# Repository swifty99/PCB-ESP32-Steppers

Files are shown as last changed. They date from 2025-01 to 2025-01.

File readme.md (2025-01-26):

# PCB-ESP32-Stepper

## Description

This project features a **PCB design for ESP32 development boards** (DevKit). It is designed to host ESP32 boards and provides a robust platform for controlling stepper motors. The PCB includes two slots for stepper motor drivers, supporting both simple drivers and more advanced ones such as **Fysetc Trinamic drivers**. Additionally, the board offers extra connectors for **I2C** or general-purpose **IOs**.

For control, the board is compatible with **FluidNC** firmware, which is a great solution for CNC machines and other motion control applications.

### Project Images

#### 3D Screenshot of the PCB
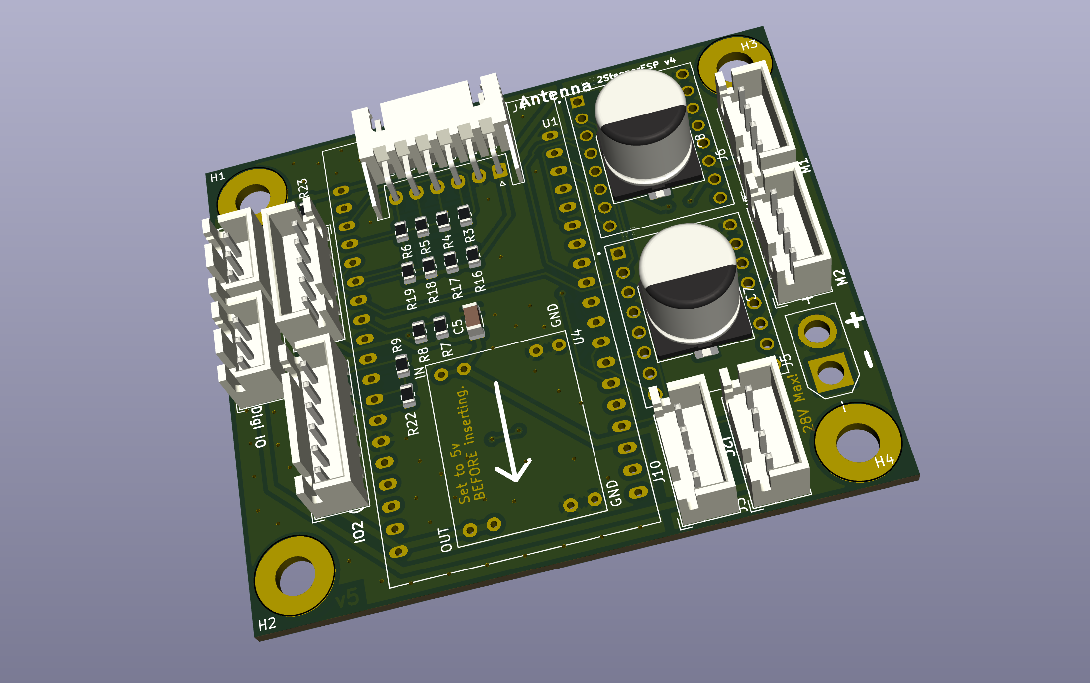
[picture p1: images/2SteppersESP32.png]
3D Screenshot


This 3D view shows the layout and components of the PCB design in KiCad.

#### Real Picture of the PCB
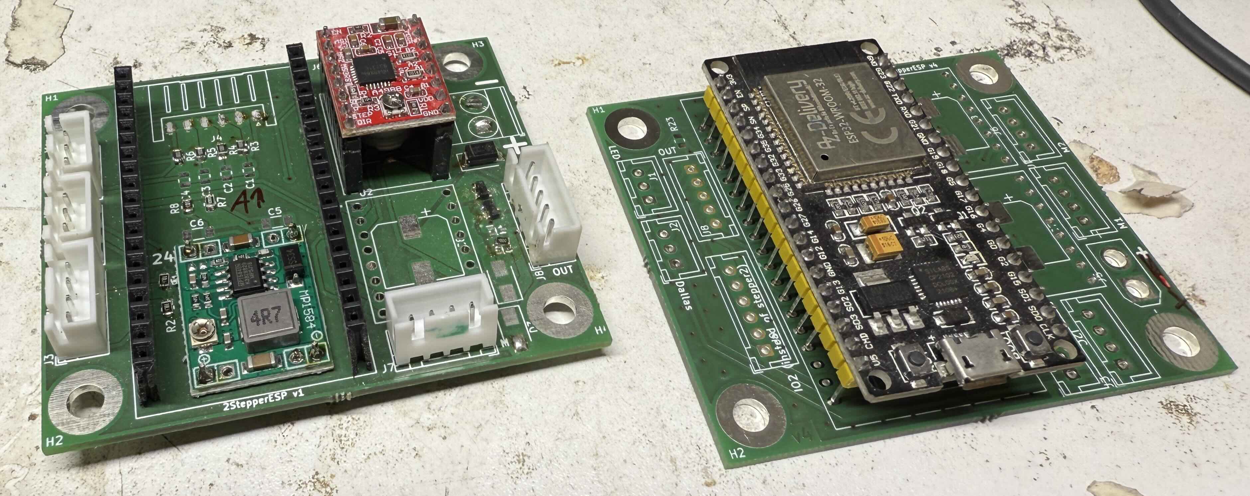
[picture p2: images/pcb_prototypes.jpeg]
Real Picture


Some prototypes. The final version is better but not yet produces

---

## Features

- **ESP32 DevKit** support for easy integration with ESP32 microcontrollers.
- **Two stepper driver slots**, compatible with:
  - Simple stepper drivers (e.g., A4988, DRV8825).
  - Advanced **Fysetc Trinamic drivers**.
- Additional **I2C** and **IO** connectors for extra peripherals.
- Two MosFETs for switching high power devices.
- Power supply support for up to **28V** (requires a mini DC-DC converter to be soldered onto the board).
- Compatible with **FluidNC** firmware for motion control applications.
- Or use with ESPHome with custom component from [SlimCDK](https://github.com/slimcdk/esphome-custom-components)

---

## Schematic and PCB

The schematic and PCB design files were created using **KiCad** and can be found [here](https://github.com/your-repository-link).

---

## Required Hardware

1. **ESP32 DevKit board** (e.g., ESP32 DevKit v1).
2. **Mini DC-DC converter** for power supply (up to 28V) – ensure you solder this onto the board for proper functionality.
3. **Stepper motor drivers**:
   - Basic drivers: A4988, DRV8825, etc.
   - Advanced drivers: Fysetc Trinamic drivers (e.g., TMC2209, TMC2208).
4. **Stepper motors** for controlling motion.
5. XT30 plug for solid power Supply

---

## Software

For controlling the board, **FluidNC** is recommended. FluidNC is open-source firmware designed for CNC machines and motion control projects. It supports various motion control features and is easy to configure for your specific needs.

- **FluidNC Firmware**: [FluidNC](http://wiki.fluidnc.com)

---

## Assembly Instructions

1. **Solder the Mini DC-DC Converter**: You need to solder a mini DC-DC converter onto the board to provide power to the system (up to 28V input).
2. **Install ESP32 DevKit**: Place your ESP32 DevKit board into the designated slot.
3. **Insert Stepper Drivers**: Insert your preferred stepper drivers into the two available slots.
4. **Connect Peripherals**: Use the additional I2C or IO connectors to integrate sensors, displays, or other components as needed.

---

## License

This project is licensed under the **MIT License**. See the `LICENSE` file for more details.

---

## Contact

For any questions or support, feel free to contact me at [your-email@example.com].

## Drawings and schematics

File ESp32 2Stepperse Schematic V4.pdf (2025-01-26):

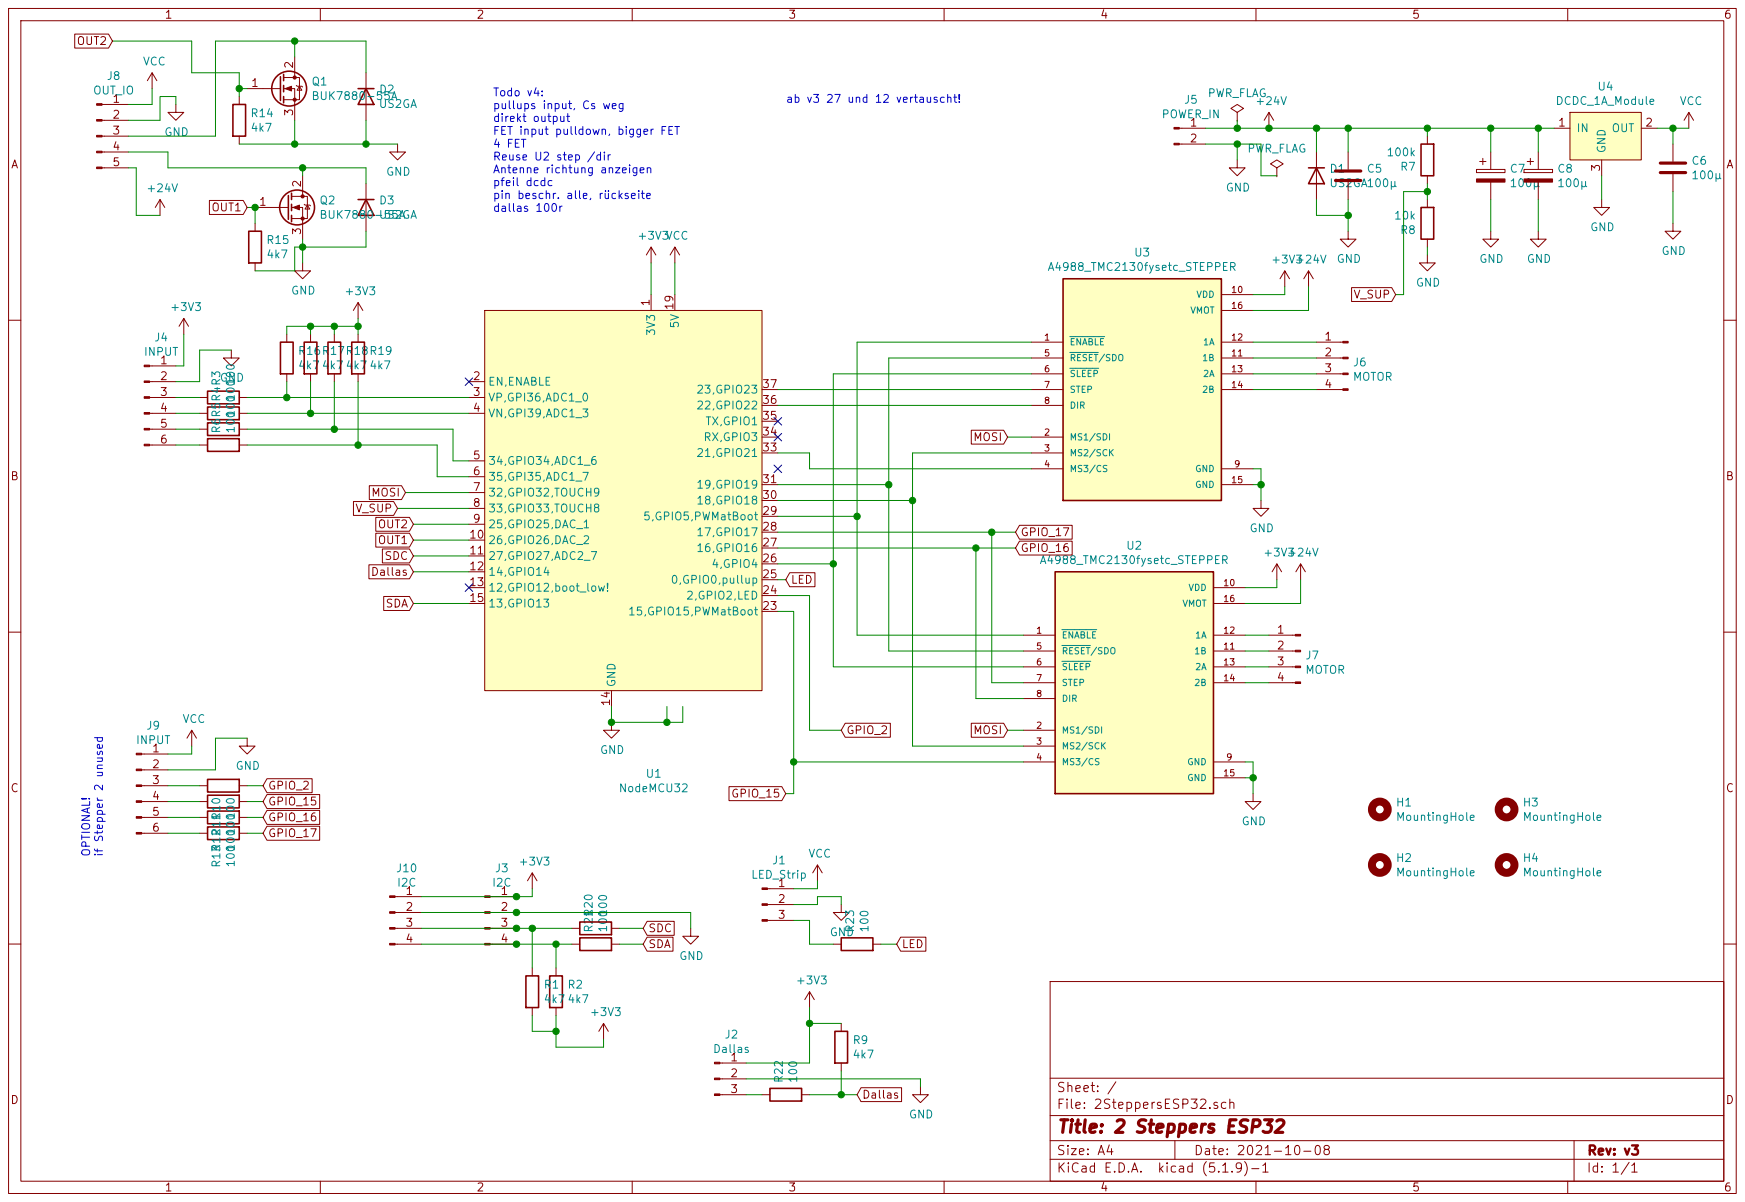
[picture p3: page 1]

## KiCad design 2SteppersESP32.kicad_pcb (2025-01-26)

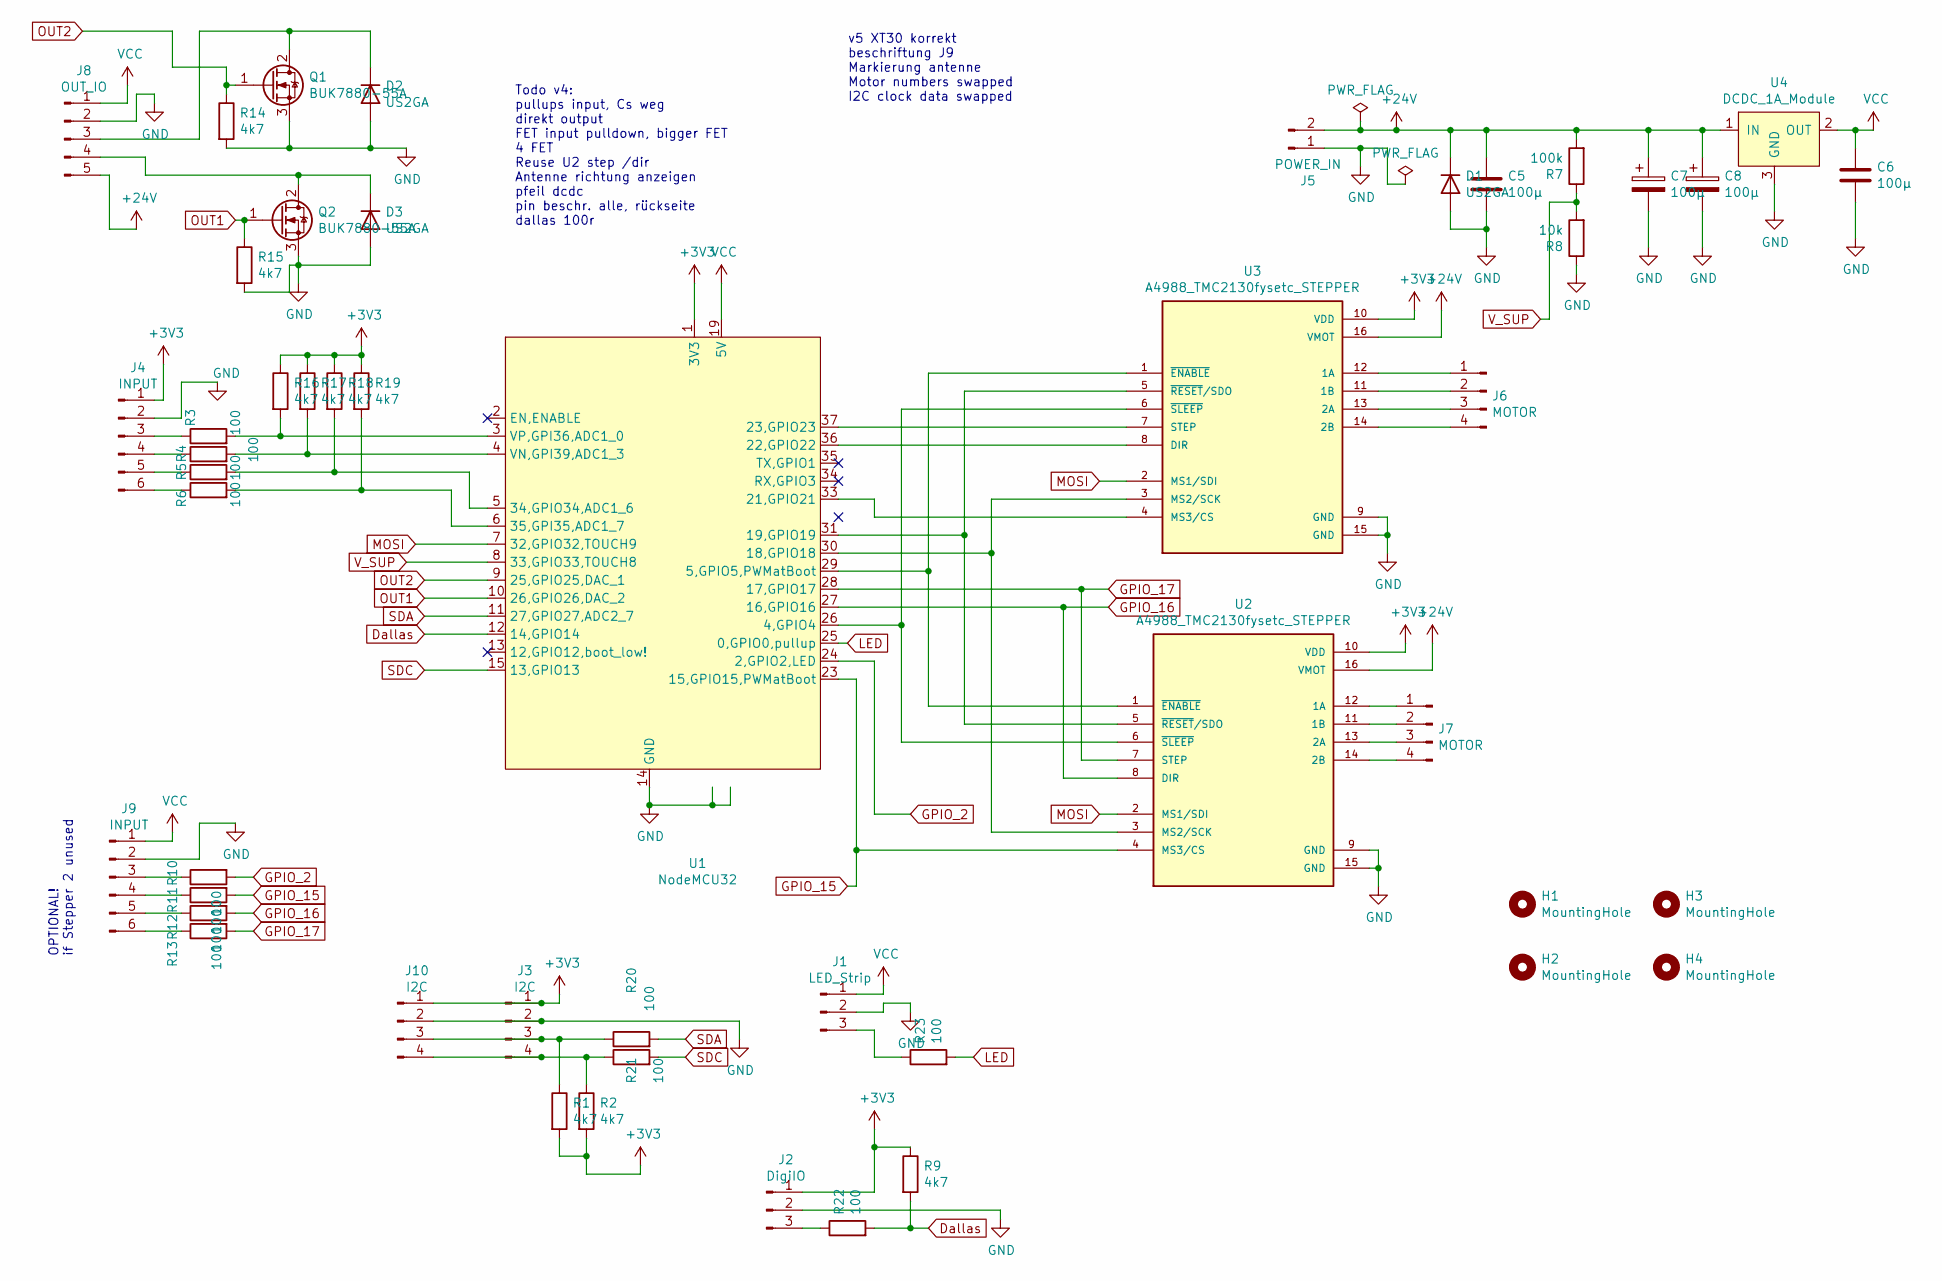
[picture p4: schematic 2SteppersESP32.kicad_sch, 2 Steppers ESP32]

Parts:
C5, C6: 100µ; C_1206_3216Metric
C7, C8: 100µ; CP_Elec_10x10
D1, D2, D3: US2GA; D_SMA
H1, H2, H3, H4: MountingHole; MountingHole_4.3mm_M4_Pad
J1: LED_Strip; JST_XH_B3B-XH-A_1x03_P2.50mm_Vertical
J2: DigiIO; JST_XH_B3B-XH-A_1x03_P2.50mm_Vertical
J3, J10: I2C; JST_XH_B4B-XH-A_1x04_P2.50mm_Vertical
J4: INPUT; JST_XH_S6B-XH-A_1x06_P2.50mm_Horizontal
J5: POWER_IN; AMASS_XT30U-F_1x02_P5.0mm_Vertical
J6, J7: MOTOR; JST_XH_B4B-XH-A_1x04_P2.50mm_Vertical
J8: OUT_IO; JST_XH_B5B-XH-A_1x05_P2.50mm_Vertical
J9: INPUT; JST_XH_B6B-XH-A_1x06_P2.50mm_Vertical
Q1, Q2: BUK7880-55A; SOT-223-3_TabPin2
R1, R2, R9, R14, R15, R16, R17, R18, R19: 4k7; R_0805_2012Metric
R3, R4, R5, R6, R10, R11, R12, R13, R20, R21, R22, R23: 100; R_0805_2012Metric
R7: 100k; R_0805_2012Metric
R8: 10k; R_0805_2012Metric
U1: NodeMCU32; ESP32_NODEMCU
U2, U3: A4988_TMC2130fysetc_STEPPER; MODULE_A4988_TMC2130_STEPPER
U4: DCDC_1A_Module; DCDC_1A_module

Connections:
+3V3: J2.1, J3.1, J4.1, J10.1, R1.2, R2.2, R9.1, R16.1, R17.1, R18.1, R19.1, U1.1 (3V3), U2.10 (VDD), U3.10 (VDD)
+24V: C5.1, C7.1, C8.1, D1.1 (K), J5.2, J8.5, R7.2, U2.16 (VMOT), U3.16 (VMOT), U4.1 (IN)
Dallas: R9.2, R22.2, U1.12 (14,GPIO14)
GND: C5.2, C6.2, C7.2, C8.2, D1.2 (A), D2.2 (A), D3.2 (A), J1.2, J2.2, J3.2, J4.2, J5.1, J8.2, J9.2, J10.2, Q1.3 (S), Q2.3 (S), R8.1, R14.2, R15.2, U1.14 (GND), U1.38 (GND), U2.9 (GND), U2.15 (GND), U3.9 (GND), U3.15 (GND), U4.3 (GND)
GPIO_2: R10.2, U1.24 (2,GPIO2,LED)
GPIO_15: R11.2, U1.23 (15,GPIO15,PWMatBoot), U2.4 (MS3/CS)
GPIO_16: R12.2, U1.27 (16,GPIO16), U2.8 (DIR)
GPIO_17: R13.2, U1.28 (17,GPIO17), U2.7 (STEP)
LED: R23.2, U1.25 (0,GPIO0,pullup)
MOSI: U1.7 (32,GPIO32,TOUCH9), U2.2 (MS1/SDI), U3.2 (MS1/SDI)
unnamed: D2.1 (K), J8.3, Q1.2 (D)
unnamed: D3.1 (K), J8.4, Q2.2 (D)
unnamed: J1.3, R23.1
unnamed: J2.3, R22.1
unnamed: J4.3, R3.1
unnamed: J4.4, R4.1
unnamed: J4.5, R5.1
unnamed: J4.6, R6.1
unnamed: J6.1, U3.12 (1A)
unnamed: J6.2, U3.11 (1B)
unnamed: J6.3, U3.13 (2A)
unnamed: J6.4, U3.14 (2B)
unnamed: J7.1, U2.12 (1A)
unnamed: J7.2, U2.11 (1B)
unnamed: J7.3, U2.13 (2A)
unnamed: J7.4, U2.14 (2B)
unnamed: J9.3, R10.1
unnamed: J9.4, R11.1
unnamed: J9.5, R12.1
unnamed: J9.6, R13.1
unnamed: J3.3, J10.3, R1.1, R20.1
unnamed: J3.4, J10.4, R2.1, R21.1
unnamed: R3.2, R16.2, U1.3 (VP,GPI36,ADC1_0)
unnamed: R4.2, R17.2, U1.4 (VN,GPI39,ADC1_3)
unnamed: R5.2, R18.2, U1.5 (34,GPIO34,ADC1_6)
unnamed: R6.2, R19.2, U1.6 (35,GPI35,ADC1_7)
unnamed: U1.26 (4,GPIO4), U2.6 (~SLEEP), U3.6 (~SLEEP)
unnamed: U1.29 (5,GPIO5,PWMatBoot), U2.1 (~ENABLE), U3.1 (~ENABLE)
unnamed: U1.30 (18,GPIO18), U2.3 (MS2/SCK), U3.3 (MS2/SCK)
unnamed: U1.31 (19,GPIO19), U2.5 (~RESET/SDO), U3.5 (~RESET/SDO)
unnamed: U1.33 (21,GPIO21), U3.4 (MS3/CS)
unnamed: U1.36 (22,GPIO22), U3.8 (DIR)
unnamed: U1.37 (23,GPIO23), U3.7 (STEP)
OUT1: Q2.1 (G), R15.1, U1.10 (26,GPIO26,DAC_2)
OUT2: Q1.1 (G), R14.1, U1.9 (25,GPIO25,DAC_1)
SDA: R21.2, U1.15 (13,GPIO13)
SDC: R20.2, U1.11 (27,GPIO27,ADC2_7)
VCC: C6.1, J1.1, J8.1, J9.1, U1.19 (5V), U4.2 (OUT)
V_SUP: R7.1, R8.2, U1.8 (33,GPIO33,TOUCH8)

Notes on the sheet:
v5 XT30 korrekt beschriftung J9 Markierung antenne Motor numbers swapped I2C clock data swapped
Todo v4: pullups input, Cs weg direkt output FET input pulldown, bigger FET 4 FET Reuse U2 step /dir Antenne richtung anzeigen pfeil dcdc pin beschr. alle, rückseite dallas 100r
OPTIONAL! if Stepper 2 unused

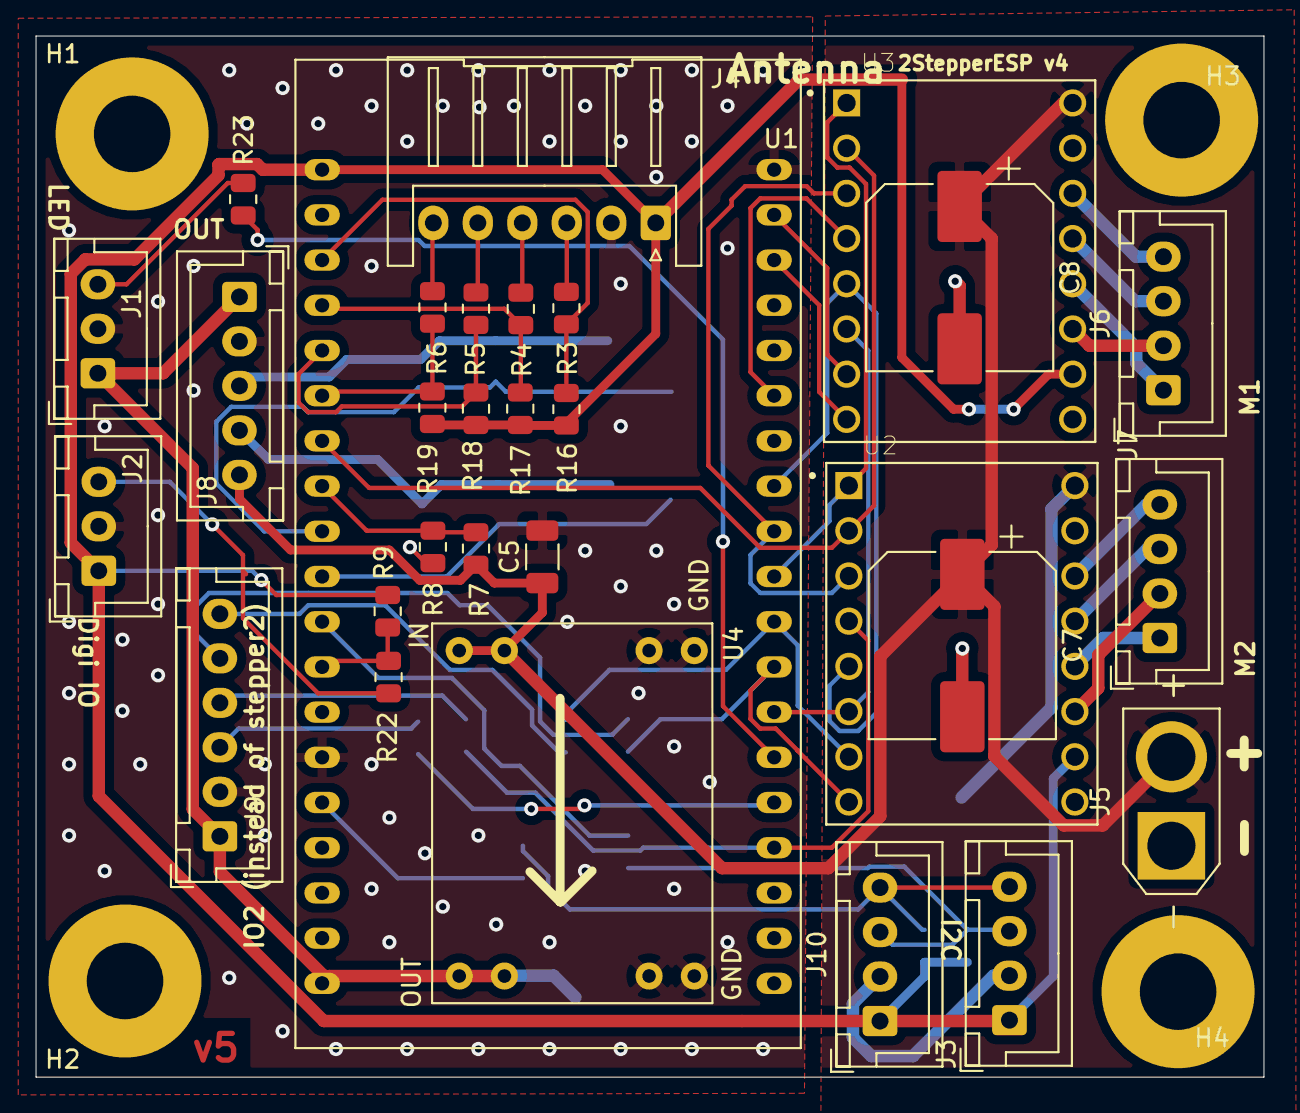
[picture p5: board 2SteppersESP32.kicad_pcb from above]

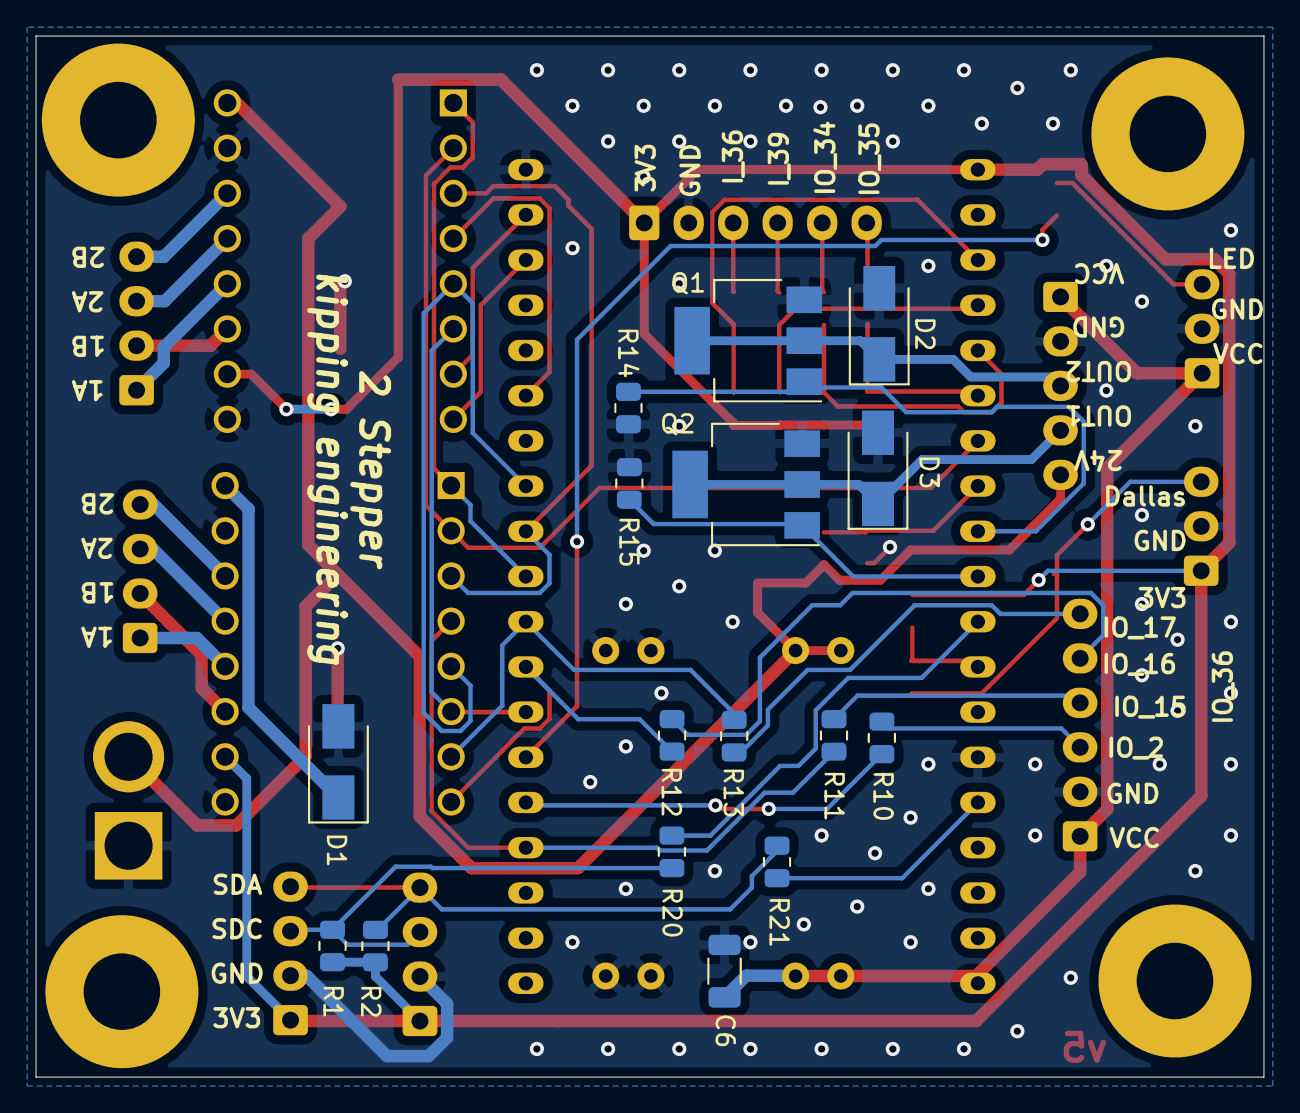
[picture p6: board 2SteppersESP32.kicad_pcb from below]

Board: 2 copper layers, 69.0 x 58.5 mm, 50 parts (16 on the bottom side), 49 nets.

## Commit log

2025-01-26 Initial commit for KiCad project
    [2SteppersESP32 - Kopie.kicad_pcb, 2SteppersESP32.kicad_pcb, 2SteppersESP32.kicad_sch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]
2025-01-26 pcb upate
    [2SteppersESP32.kicad_pcb]
2025-01-26 pcb images
2025-01-26 Rename pcb prototypes.jpeg to pcb_prototypes.jpeg
